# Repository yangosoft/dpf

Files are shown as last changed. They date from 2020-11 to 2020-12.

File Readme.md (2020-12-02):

# Diesel Filter Particle viewer

Only tested in a Volkswagen 2.0 TDI CAGA engine.

The code is mostly based on https://github.com/fkoca5055/obdESP with some changes to check DFP status, provide a WiFi Access Point to change Bluetooth device, PIN, debug viewer...

Please note: as I'm not having so much time to spend on this project the code is quick and dirty.

## Needed parts

 - ESP32 NodeMCU ESP-32s
 - TFT Screen based on ILI9341
 - ELM327 Bluetooth

## Box and schema

 - [PCB](schema/dpf1) designed with EAGLE.
 - [Box to 3d print](schema/3dmodel) designed with FreeCAD.

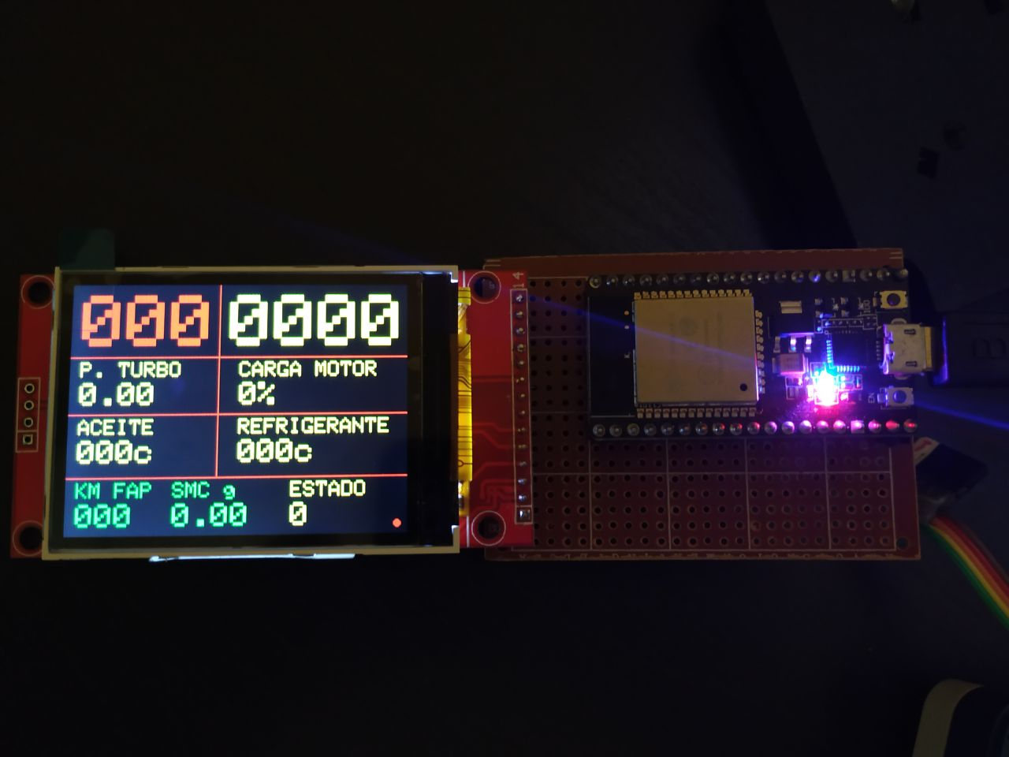
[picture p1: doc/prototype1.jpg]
Prototype1

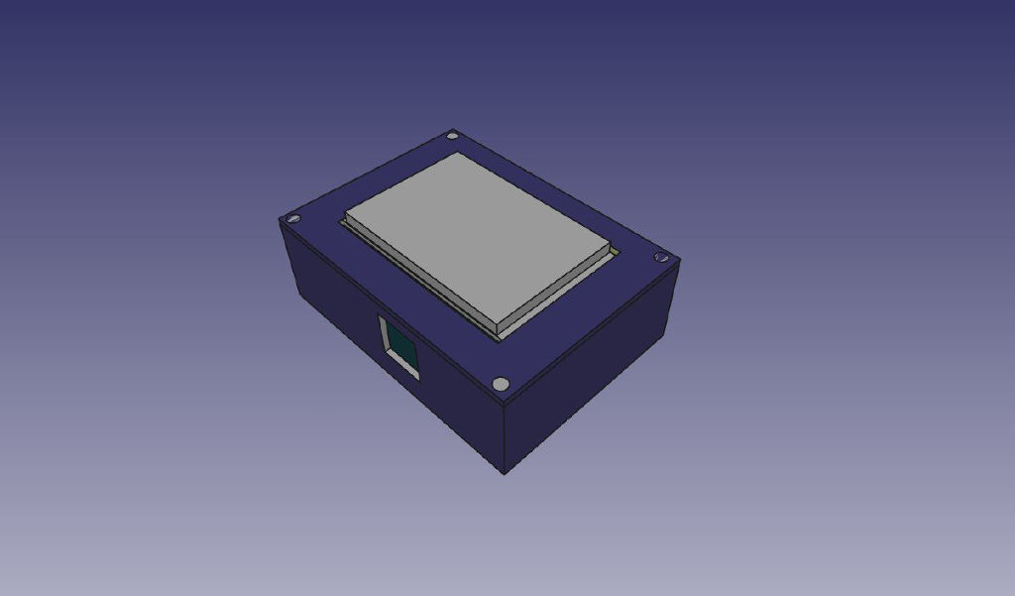
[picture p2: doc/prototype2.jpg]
Prototype2

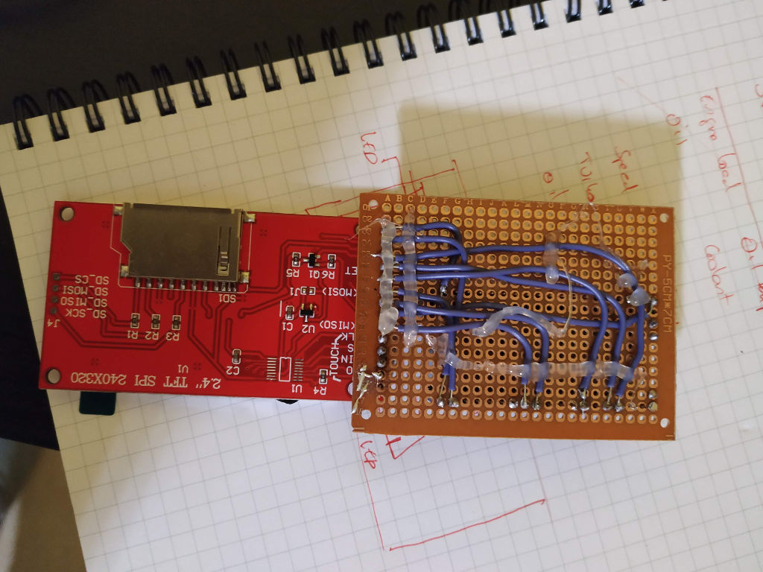
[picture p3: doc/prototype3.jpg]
Prototype3

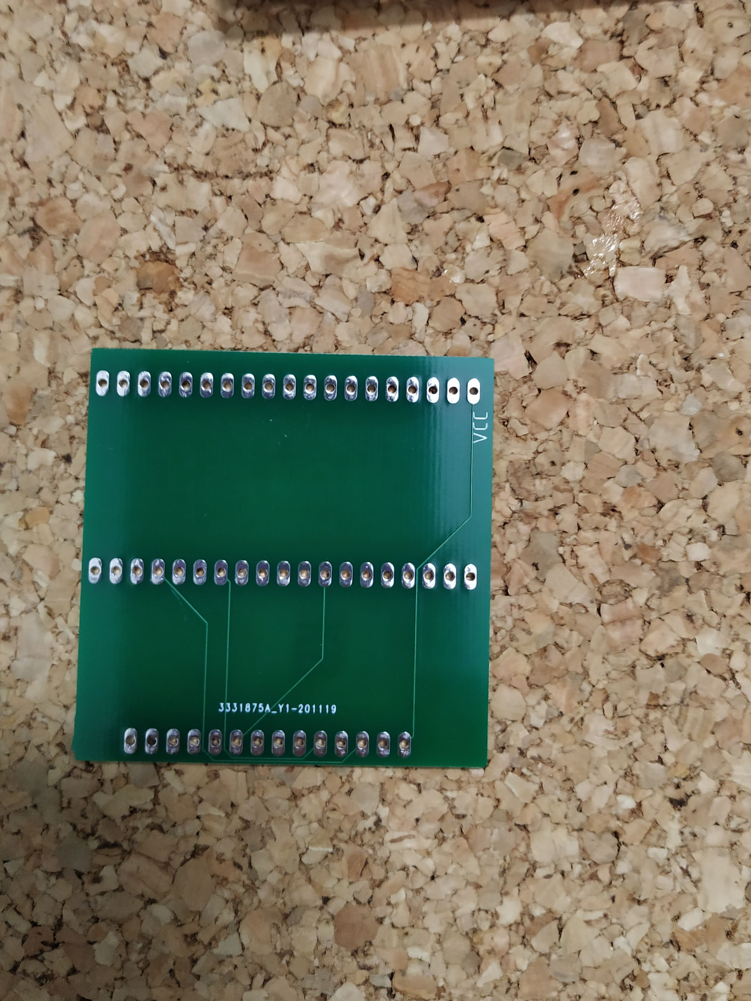
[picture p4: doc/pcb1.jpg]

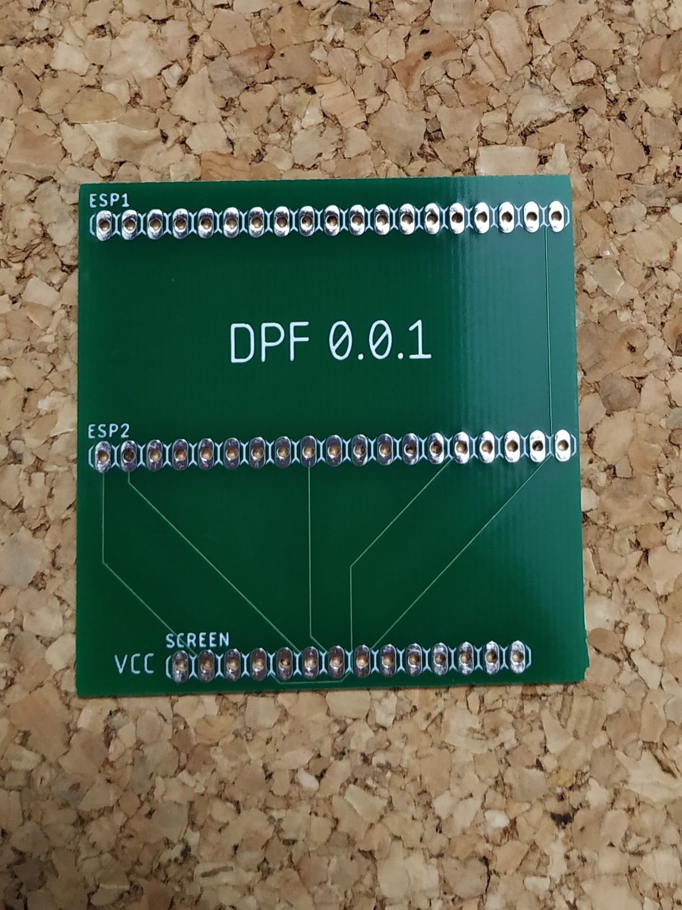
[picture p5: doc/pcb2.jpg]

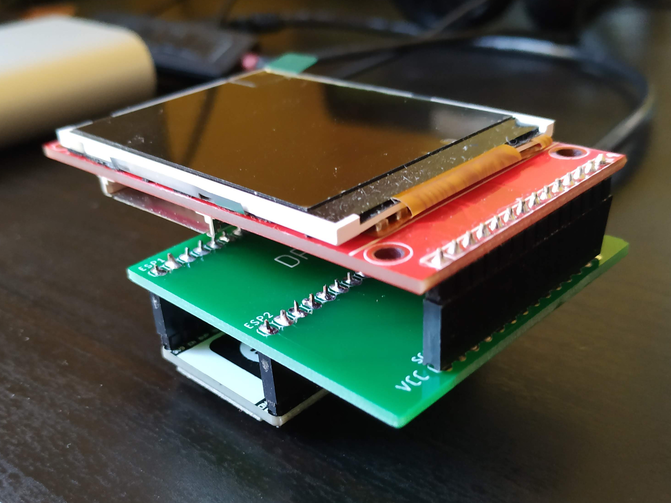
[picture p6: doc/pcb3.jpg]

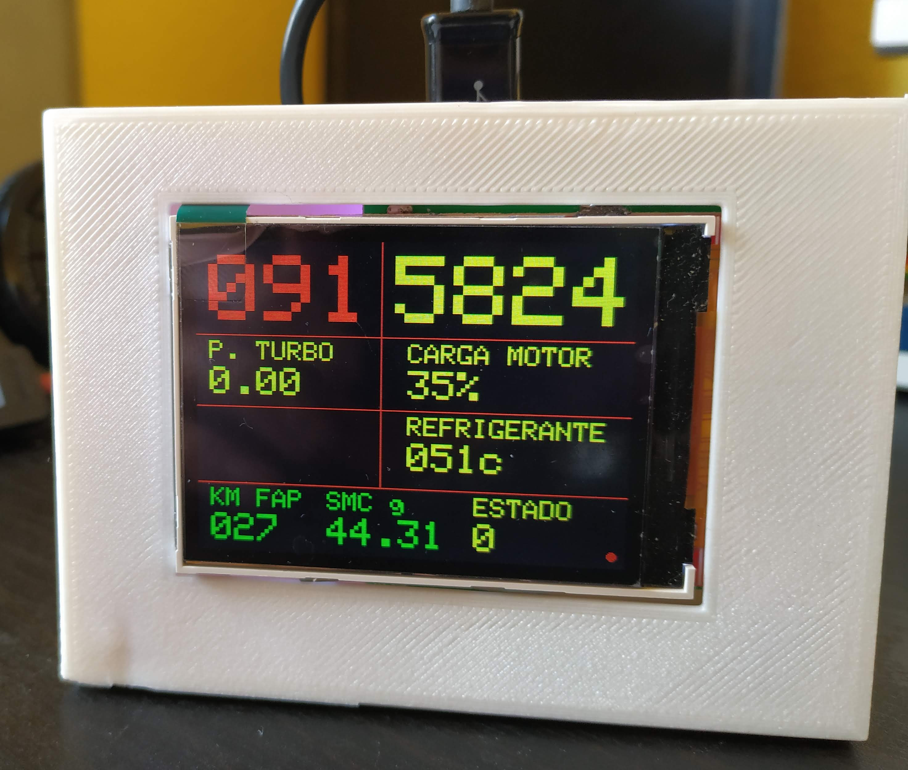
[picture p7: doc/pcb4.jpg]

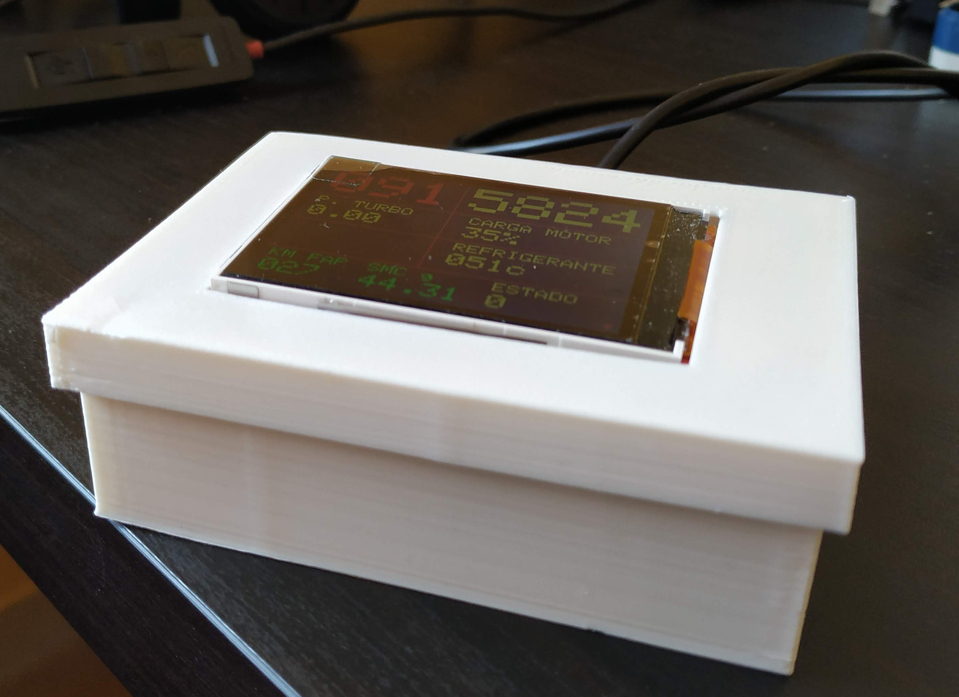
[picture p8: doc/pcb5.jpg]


## Pinout

|  TFT | ESP32 GPIO |
|---|---|
| TFT_CS | 15 |
| TFT_DC | 4 |
| TFT_MOSI | 23 |
| TFT_SLK | 18 |
| TFT_RST | 2 |
| TFT_LED | -1 |
| TFT_MISO | 19 |

Please change `TFT_RST` to another GPIO since this the integrated led in `NodeMCU ESP-32s`.

# Next steps

Remove the screen and make use of the FIS to display DFP information

# Useful links

- https://stackoverflow.com/questions/23877761/sniffing-logging-your-own-android-bluetooth-traffic
- https://forums.tdiclub.com/index.php?threads/reading-soot-level-with-torque.464119/page-4
- https://github.com/fkoca5055/obdESP/blob/master/2.4_LCD.ino
- https://www.cardumps.net/account/my-profile
- https://stackoverflow.com/questions/23877761/sniffing-logging-your-own-android-bluetooth-traffic
- http://jakubdziworski.github.io/obd/bluetooth/arduino/car/2020/07/13/arduino-obd-dpf-monitor-insignia.html
- http://www.areavag.com/foro/showthread.php?42159-Regeneraci%F3n-filtro-part%EDculas-diagnosis-con-iPhone/page3
- https://gist.github.com/0/c73e2557d875446b9603
- https://stackoverrun.com/es/q/12573350
- http://jakubdziworski.github.io/
- https://scribles.net/setting-up-bluetooth-serial-port-profile-on-raspberry-pi/
- https://forum.fairphone.com/t/location-of-btsnoop-hci-log-file/60320
- https://www.fte.com/WebHelpII/Sodera/Content/Documentation/WhitePapers/BPA600/Encryption/GettingAndroidLinkKey/RetrievingHCIlog.htm
- https://stackoverflow.com/questions/23877761/sniffing-logging-your-own-android-bluetooth-traffic
- https://github.com/fkoca5055/obdESP
- https://github.com/ibanezgomez/FISBlocks

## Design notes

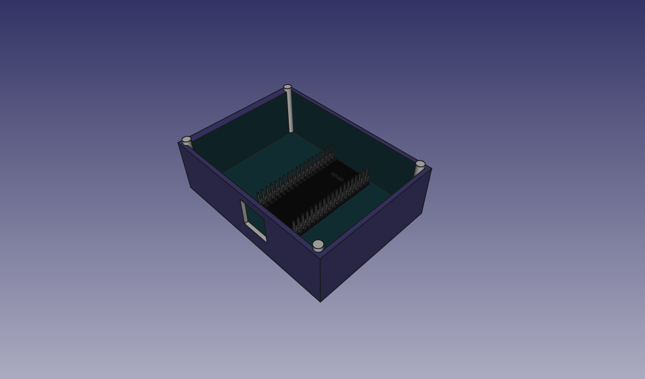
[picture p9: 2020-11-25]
schema/3dmodel/complete3.png

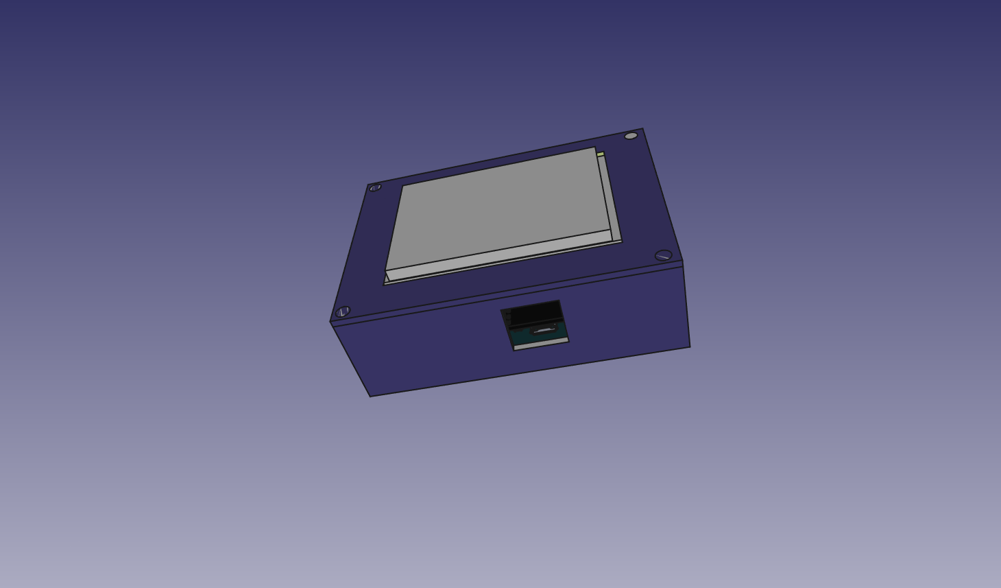
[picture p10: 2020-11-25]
schema/3dmodel/complete5.png

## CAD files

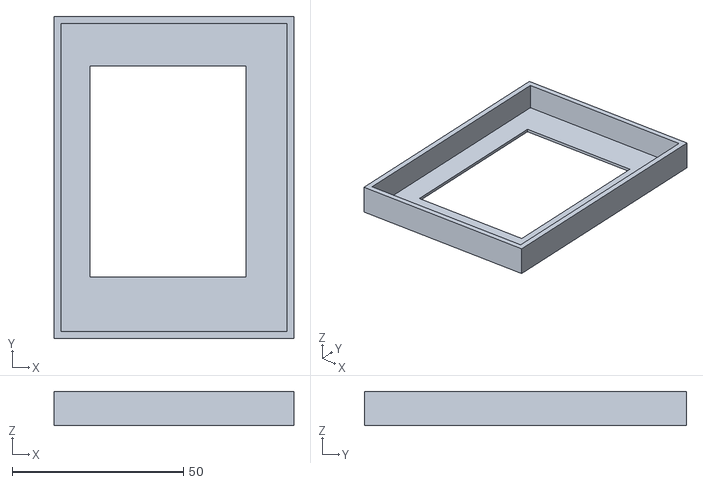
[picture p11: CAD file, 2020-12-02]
schema/3dmodel/outbox1-v4.stl
70.0 x 94.0 x 10.0

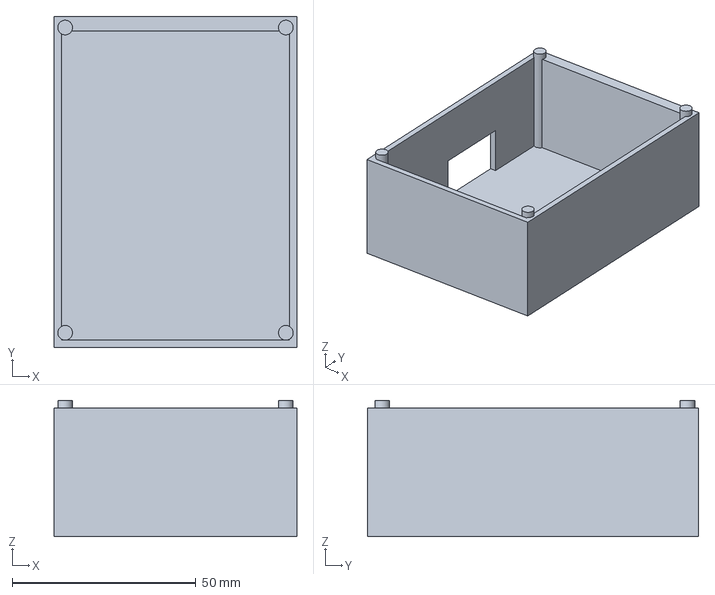
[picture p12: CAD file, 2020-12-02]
schema/3dmodel/outbox2-v2.FCStd
66.0 x 90.0 x 37.0 mm

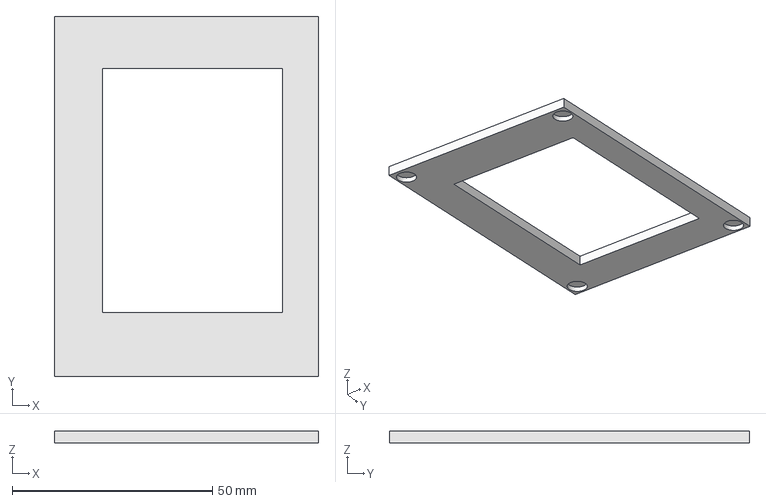
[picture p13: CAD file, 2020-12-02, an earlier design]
schema/3dmodel/outbox1-v2.FCStd
66.0 x 90.0 x 3.00 mm

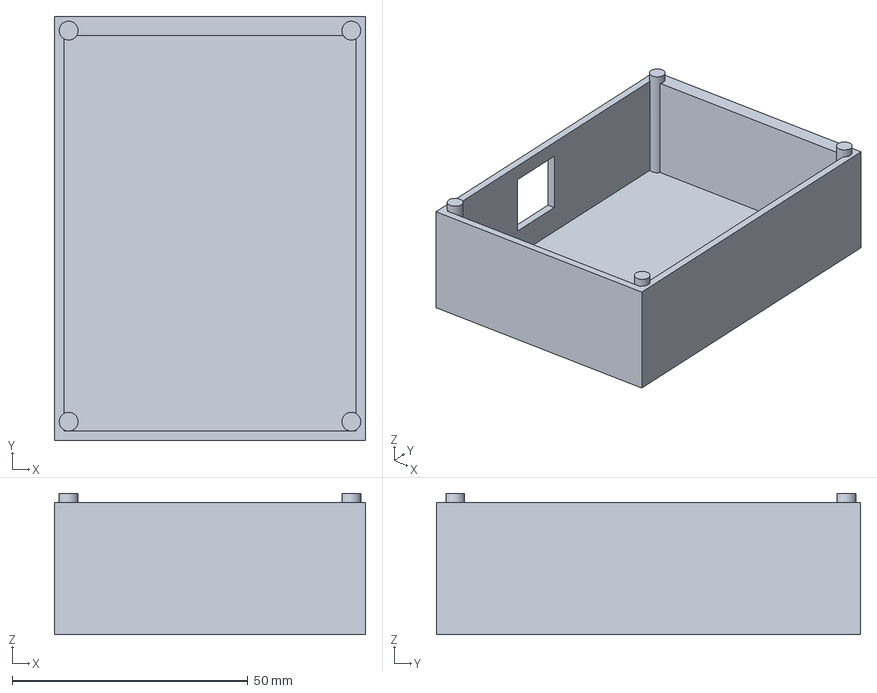
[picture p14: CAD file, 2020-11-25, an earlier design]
schema/3dmodel/outbox2.FCStd
66.0 x 90.0 x 30.0 mm

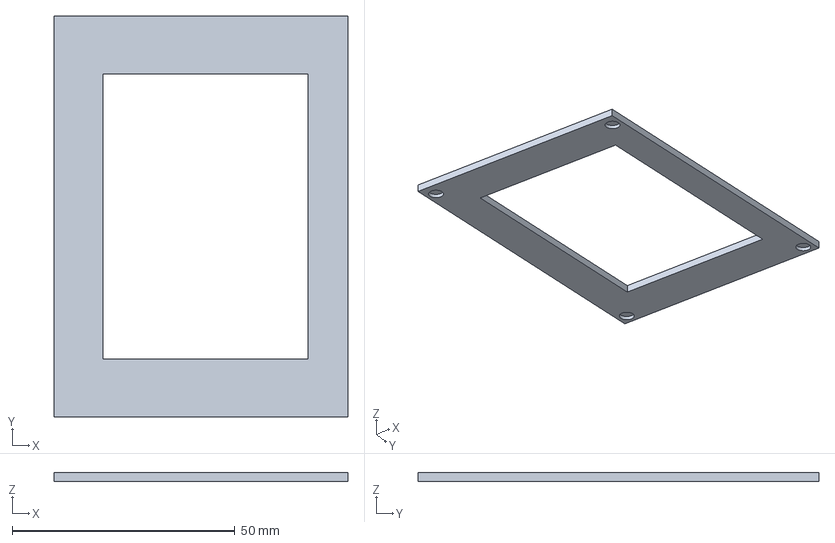
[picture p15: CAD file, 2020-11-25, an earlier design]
schema/3dmodel/outbox1.FCStd
66.0 x 90.0 x 2.00 mm

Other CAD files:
schema/3dmodel/outbox1-v3.FCStd
schema/3dmodel/outbox1-v2.stl
schema/3dmodel/outbox1-v3.stl
schema/3dmodel/outbox1.stl
schema/3dmodel/outbox2-v2.stl
schema/3dmodel/outbox2.stl

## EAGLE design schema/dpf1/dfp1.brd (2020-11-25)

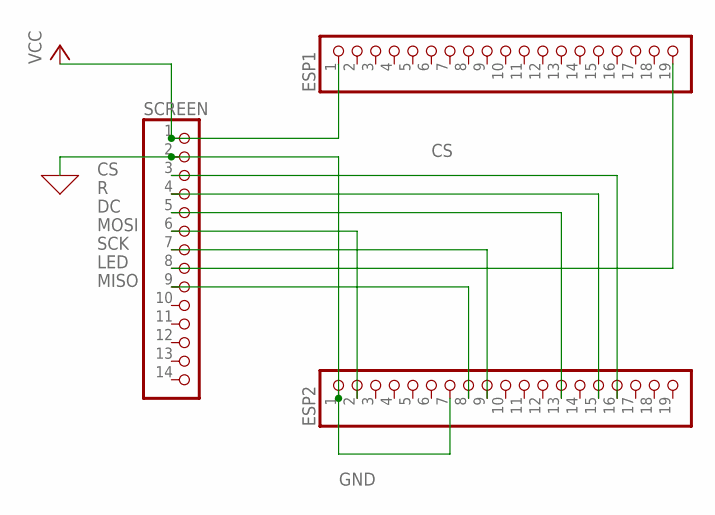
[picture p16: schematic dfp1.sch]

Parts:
ESP1, ESP2: PINHD-1X19; 1X19
SCREEN: PINHD-1X14; 1X14

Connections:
CS: ESP2.16, SCREEN.3
DC: ESP2.13, SCREEN.5
GND: ESP2.1, ESP2.7, SCREEN.2
LED: ESP1.19, SCREEN.8
MISO: ESP2.8, SCREEN.9
MOSI: ESP2.2, SCREEN.6
R: ESP2.15, SCREEN.4
SCK: ESP2.9, SCREEN.7
VCC: ESP1.1, SCREEN.1

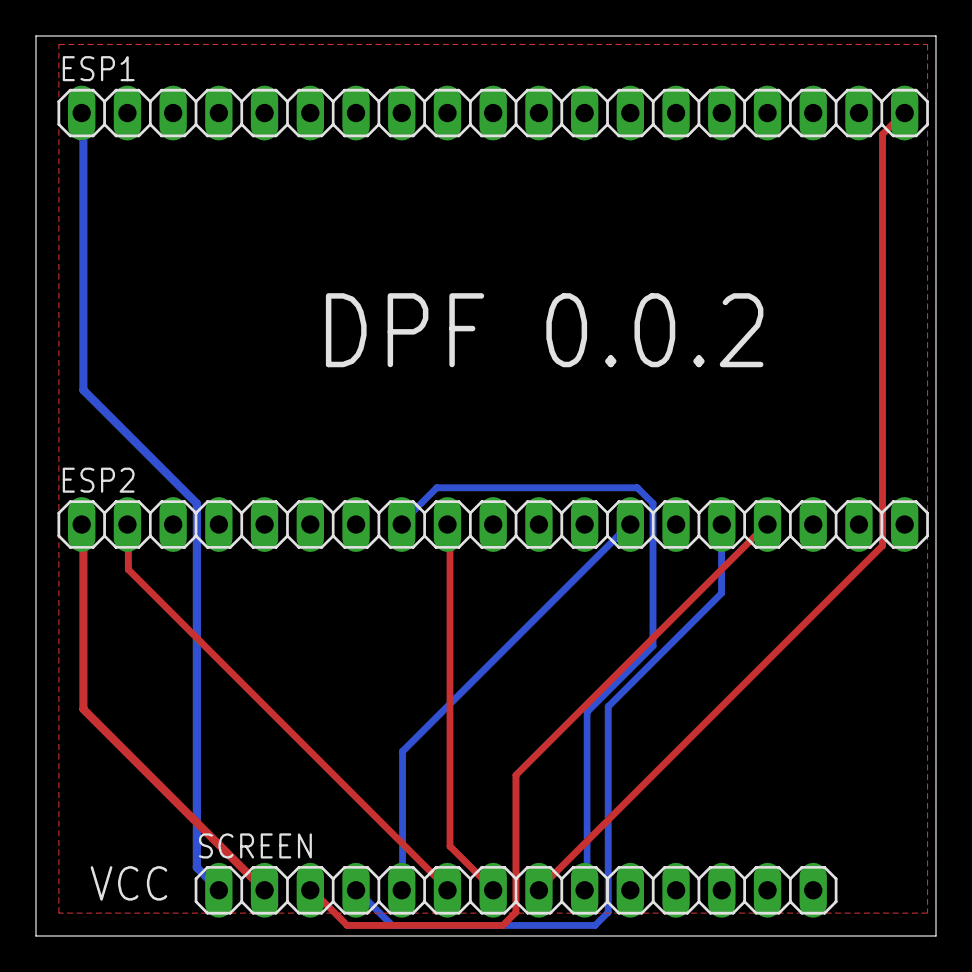
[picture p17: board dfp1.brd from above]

Board: 2 copper layers, 50.0 x 50.0 mm, 3 parts (0 on the bottom side), 9 nets.

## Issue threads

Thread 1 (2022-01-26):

Question about values

Dropsik, 2022-01-26:
Hi. I ported yours code into Arduino and it works pretty well (but it's more dirty :) )
I can't figure, why I'm getting few values (and I'm not sure it's a problem with code or PIDs).

- turboPRESS always show value >=1.0 (even when engine is off, it showing 1.0)
- oilTemp show always -30 (even FIS showing >70)
and the bigger mess, is when I try call getSMC() - everywhere I got wrong values (like 2524 for RPM when I don't touch throttle) - for few second I see good values.
I'm working with Audi A4 B8 (CNHA engine)

yangosoft, 2022-01-27:
Hi!

Check the data that you are getting.

Print the bytes one to one and try to do the calculations by hand.

It could be also that your OBD2 dongle is not sending the data.

I'm not totally sure if B8  PIDs are different from B7 but at least the standard one must be the same.

BR,
yango

Dropsik, 2022-01-27:
After few tests:
- oilTemp is not supported in my car
- getSMC() function retrieve correct value (checked with VCDS), but after call this funtion it's completly stop refreshing data.

Dropsik, 2022-01-27:
Ok, I made a little debuging
getRpm();
getSpeed();
getBattery();
getTurboPressure();
getEngineLoad();
getEGT();
getCoolant();
works perfect and give reliable data until I call getSMC();
SEND_BLE("ATSH7E0\r"); cause that I got reliable data for DPF, but completly random for these above.

yangosoft, 2022-01-28:
Make sure you only send ATSH7E0 once. This sets the ELM327 to use 7bits CAN messages, if I'm not wrong.

And remember to reset all stored values in ELM327.

Dropsik, 2022-01-28:
I'm using initODB() from your code - so ATD is sent.
And funny thing - you send ATSH7E0 twice ;)
https://github.com/yangosoft/dpf/blob/master/src/dpf.cpp#L275
https://github.com/yangosoft/dpf/blob/master/src/dpf.cpp#L487

Dropsik, 2022-01-29:
My source code:
https://github.com/Dropsik/dpf/blob/master/arduino/obd2/obd2.ino

yangosoft, 2022-02-08:
@Dropsik did you manage to get fully working?

Dropsik, 2022-02-09:
Unfortunately no.
I assume, that my elm327 adapter is ok (works with android app and show values). But I have no idea how to resolve problem

Dropsik, 2022-02-14:
@yangosoft If you have any ideas or maybe the can try my code I'll be appreciated help.

yangosoft, 2022-02-14:
Sadly I sold my nice car a few months ago and I don't have access to a CAGA engine.

Try to debug the Bluetooh traffic between an app and the device: https://stackoverflow.com/questions/23877761/sniffing-logging-your-own-android-bluetooth-traffic this should give you a hint about the correct sequence of commands.

Closed 2023-04-04.

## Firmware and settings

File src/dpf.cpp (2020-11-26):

#include "dpf.hpp"

Adafruit_ILI9341 tft = Adafruit_ILI9341(TFT_CS, TFT_DC, TFT_MOSI, TFT_SLK, TFT_RST, TFT_MISO);

char rxData[READ_BUFFER_SIZE];
uint8_t rxIndex = 0;

int rpm, LDR, LDRMAX, LDRMIN, EGT, turboRAW, reading, COOLANT, x, engineLoad, oilTemp;
uint32_t speed;
byte INTEMP, CACT, SPEED;
float BATTERY, turboPRESS, turboMAX;

unsigned long time_now2 = 0;
unsigned long period2 = 10000; 
unsigned long time_now5 = 0;
unsigned long period5 = 30000; 
unsigned long delayTime = 0;   

uint16_t SMC;
uint32_t km;
uint8_t percentFap;

char iBuf[16] = {};
char eBuf[16] = {};
char cBuf[16] = {};
char oBuf[16] = {};


BluetoothSerial SerialBT;

String name = "obd-2";
String pin = "1234";

String WIFI_CLIENT;
String WIFI_CLIENT_PASS;
String LOCAL_NAME;

AsyncWebServer server(80);
AsyncWebSocket ws("/ws");

void writeFile(fs::FS &fs, const char *path, const char *message)
{
  //Serial.printf("Writing file: %s\r\n", path);
  File file = fs.open(path, "w");
  if (!file)
  {
    //Serial.println("- failed to open file for writing");
    return;
  }

  file.print(message);
}

String readFile(fs::FS &fs, const char *path)
{
  //Serial.printf("Reading file: %s\r\n", path);
  File file = fs.open(path, "r");
  if (!file)
  {
    Serial.println("- empty file or failed to open file");

    return String();
  }
  //Serial.println("- read from file:");
  String fileContent;
  while (file.available())
  {
    fileContent += String((char)file.read());
  }
  //Serial.println(fileContent);
  return fileContent;
}

void handleRoot(AsyncWebServerRequest *request)
{
  request->send_P(200, "text/html", FRM_PASS);
}

void handleSave(AsyncWebServerRequest *request)
{
  if (request->hasParam(PARAM_INPUT_1))
  {
    WIFI_CLIENT = request->getParam(PARAM_INPUT_1)->value();
    writeFile(SPIFFS, "/wifi1", WIFI_CLIENT.c_str());
  }

  if (request->hasParam(PARAM_INPUT_2))
  {
    WIFI_CLIENT_PASS = request->getParam(PARAM_INPUT_2)->value();
    writeFile(SPIFFS, "/wifi2", WIFI_CLIENT_PASS.c_str());
  }

  if (request->hasParam(PARAM_INPUT_3))
  {
    LOCAL_NAME = request->getParam(PARAM_INPUT_3)->value();
    writeFile(SPIFFS, "/wifi3", LOCAL_NAME.c_str());
  }

  char buffer[256];
  snprintf(buffer, 256, "%s %s %s", WIFI_CLIENT.c_str(), WIFI_CLIENT_PASS.c_str(), LOCAL_NAME.c_str());

  request->send_P(200, "text/html", buffer);
}

void getStoredParams()
{
  WIFI_CLIENT = readFile(SPIFFS, "/wifi1");
  WIFI_CLIENT_PASS = readFile(SPIFFS, "/wifi2");
  LOCAL_NAME = readFile(SPIFFS, "/wifi3");

  Serial.print("WIFI_CLIENT: ");
  Serial.println(WIFI_CLIENT);
  Serial.print("WIFI_CLIENT_PASS: ");
  Serial.println(WIFI_CLIENT_PASS);
  Serial.print("LOCAL_NAME: ");
  Serial.println(LOCAL_NAME);
  if (LOCAL_NAME == "")
  {
    LOCAL_NAME = "obd-2";
  }

  if (WIFI_CLIENT == "")
  {
    WIFI_CLIENT = "1234";
  }
}

void onEvent(AsyncWebSocket *server, AsyncWebSocketClient *client, AwsEventType type, void *arg, uint8_t *data, size_t len)
{
  switch (type)
  {
  case WS_EVT_CONNECT:
    Serial.printf("WebSocket client #%u connected from %s\n", client->id(), client->remoteIP().toString().c_str());
    break;
  case WS_EVT_DISCONNECT:
    Serial.printf("WebSocket client #%u disconnected\n", client->id());
    break;
  case WS_EVT_DATA:
    //handleWebSocketMessage(arg, data, len);
    break;
  case WS_EVT_PONG:
  case WS_EVT_ERROR:
    break;
  }
}

void setup()
{
  Serial.begin(115200);

  if (!SPIFFS.begin())
  {
    Serial.println("An Error has occurred while mounting SPIFFS");
  }
  Serial.println("Get params()");
  getStoredParams();
  Serial.println("OK!");
  name = LOCAL_NAME;
  pin = WIFI_CLIENT;
  Serial.println("ACCESS POINT MODE");
  Serial.print("Configuring access point...");
  WiFi.softAP(ssid, password);

  IPAddress myIP = WiFi.softAPIP();
  Serial.print("AP IP address: ");
  Serial.println(myIP);
  server.on("/", HTTP_GET, handleRoot);
  server.on("/save", HTTP_GET, handleSave);
  ws.onEvent(onEvent);
  server.addHandler(&ws);
  server.begin();

  SerialBT.begin("dpfread", true);
  SerialBT.setPin(pin.c_str());

  tft.begin();
  tft.setRotation(1);
  tft.fillScreen(ILI9341_WHITE);

  tft.setCursor(250, 230);
  tft.setTextSize(1);
  tft.setTextColor(ILI9341_BLACK, ILI9341_WHITE);
  tft.print(VERSION);

  tft.setCursor(0, 20);
  tft.setTextSize(2);
  tft.setTextColor(ILI9341_BLACK, ILI9341_WHITE);

  tft.print("WIFI: ");
  tft.print(ssid);
  tft.print("\n\nPASS: ");
  tft.print(password);
  tft.print("\n\n");

  tft.print("Bluetooth: ");
  tft.print(name);
  tft.print("\n\nPIN: ");
  tft.print(pin);
  tft.print("\n\n");

  delay(5000);

  bool connected = SerialBT.connect(name);
  while (connected == false)
  {
    Serial.println("Connecting...");
    delay(500);
  }
  tft.fillScreen(ILI9341_WHITE);
  tft.setCursor(0, 10);
  tft.setTextSize(1);
  //SerialBT.flush();
  Serial.println("Init ODB");
  tft.print("Init ELM327\n\n");
  initODB();
  tft.fillScreen(ILI9341_BLACK);

  tft.drawLine(0, 70, 320, 70, ILI9341_RED);
  tft.drawLine(0, 125, 320, 125, ILI9341_RED);
  tft.drawLine(0, 185, 320, 185, ILI9341_RED);
  tft.drawLine(140, 0, 140, 185, ILI9341_RED);

  drawScreen(false);
}

void loop()
{
  ws.cleanupClients();
  getRpm();
  getSpeed();
  getTurboPressure();
  getEngineLoad();

  if (millis() > time_now2 + period2)
  {
    //getIntakeTemperature();
    getCoolant();
    getOilTemp();
    time_now2 = millis();
    //drawScreen(false);
  }
  else if (millis() > time_now5 + period5)
  {
    getSMC();
    time_now5 = millis();
    drawScreen(false);
  }
  else
  {
    drawScreen(true);
  }
}

void initODB()
{
  delay(0); //1000
  SEND_BLE("ATZ\r");
  delay(500); //2000
  readOBD();
  SEND_BLE("ATD\r");
  delay(500); //2000
  readOBD();
  tft.print(rxData);
  tft.print("\n");
  SEND_BLE("ATE0\r");
  delay(500); //1000
  readOBD();
  tft.print(rxData);
  tft.print("\n");
  SEND_BLE("ATSP6\r");
  delay(500); //1000
  readOBD();
  tft.print(rxData);
  tft.print("\n");
  SEND_BLE("ATSH7E0\r");
  delay(700);
  readOBD();
  tft.print(rxData);
  tft.print("\n");
  //SerialBT.flush();
}

void drawScreen(bool half)
{
  static int randomColor = 0;
 

  tft.setCursor(10, 10);
  tft.setTextColor(ILI9341_RED, ILI9341_BLACK);
  tft.setTextSize(7);
  snprintf(oBuf, sizeof(oBuf), "%03d", speed);
  tft.print(oBuf);

  tft.setCursor(150, 10);
  tft.setTextColor(ILI9341_YELLOW, ILI9341_BLACK);
  tft.setTextSize(7);
  snprintf(oBuf, sizeof(oBuf), "%04d", rpm);
  tft.print(oBuf);

  tft.setCursor(10, 75);
  tft.setTextSize(2);
  tft.print("P. TURBO");

  tft.setCursor(10, 95);
  tft.setTextSize(3);
  tft.print(turboPRESS, 2);

  tft.setTextSize(2);
  tft.setCursor(160, 75);
  tft.setTextColor(ILI9341_YELLOW, ILI9341_BLACK);
  tft.print("CARGA MOTOR");

  tft.setTextSize(3);
  tft.setCursor(160, 95);
  tft.setTextColor(ILI9341_YELLOW, ILI9341_BLACK);
  tft.print(engineLoad);
  tft.print("%");

  if (randomColor % 2)
  {
    tft.fillCircle(310, 230, 3, ILI9341_BLACK);
  }
  else
  {
    tft.fillCircle(310, 230, 3, ILI9341_RED);
  }

  randomColor++;

  if (half == true)
  {
    return;
  }

  /* Not supported :(
  tft.setCursor(10, 130);
  tft.setTextSize(2);
  tft.print("ACEITE");
  tft.setTextSize(3);
  tft.setCursor(10, 150);
  snprintf(oBuf, sizeof(oBuf), "%03d", oilTemp);
  tft.print(oBuf);
  tft.println("c");*/

  tft.setCursor(160, 130);
  tft.setTextSize(2);
  tft.print("REFRIGERANTE");
  tft.setTextSize(3);
  tft.setCursor(160, 150);
  snprintf(oBuf, sizeof(oBuf), "%03dc", COOLANT);
  tft.print(oBuf);

  tft.setCursor(210, 190);
  tft.setTextSize(2);
  tft.print("ESTADO");

  tft.setCursor(210, 210);
  tft.setTextSize(3);
  tft.print(percentFap);

  float SMCF = SMC;
  SMCF = SMCF / 100;
  tft.setTextColor(ILI9341_GREEN, ILI9341_BLACK);
  tft.setTextSize(2);
  tft.setCursor(100, 190);
  tft.print("SMC g");
  tft.setTextSize(3);
  char buffer[16];
  snprintf(buffer, 16, "%.2f", SMCF);
  tft.setCursor(100, 210);
  tft.print(buffer);

  tft.setTextColor(ILI9341_GREEN, ILI9341_BLACK);
  tft.setTextSize(2);
  tft.setCursor(10, 190);
  tft.print("KM FAP");
  tft.setTextSize(3);
  tft.setCursor(10, 210);
  snprintf(buffer, 16, "%03d", km);
  tft.print(buffer);
}

void getRpm()
{
  SerialBT.flush();
  SEND_BLE("010C\r");
  delay(delayTime);
  readOBD();
  rpm = ((strtol(&rxData[6], 0, 16) * 256) + strtol(&rxData[9], 0, 16)) / 4;
}

void getEngineLoad()
{
  SerialBT.flush();
  SEND_BLE("0104\r");
  delay(delayTime);
  readOBD();
  engineLoad = (strtol(&rxData[6], 0, 16) * 100) / 255;
}

void getCoolant()
{
  SerialBT.flush();
  SEND_BLE("0105\r");
  delay(delayTime);
  readOBD();
  COOLANT = strtol(&rxData[6], 0, 16) - 40;
}

//
void getOilTemp()
{
  SerialBT.flush();
  SEND_BLE("015C\r");
  delay(delayTime);
  readOBD();
  oilTemp = strtol(&rxData[6], 0, 16) - 40;
}

void getIntakeTemperature()
{
  SerialBT.flush();
  SEND_BLE("010F\r");
  delay(delayTime);
  readOBD();
  INTEMP = strtol(&rxData[6], 0, 16) - 40;
  tft.setCursor(220, 0);
  tft.setTextColor(ILI9341_GREEN, ILI9341_BLACK);
  tft.setTextSize(2);
  tft.print("T. AIRE");
  tft.setTextSize(3);
  tft.setCursor(225, 25);
  snprintf(iBuf, sizeof(iBuf), "%3d", INTEMP);
  tft.println(iBuf);
  tft.setCursor(290, 25);
  tft.println("c");
  tft.drawCircle(285, 25, 3, ILI9341_GREEN);
}

void getCACT()
{
  SerialBT.flush();
  SEND_BLE("0177\r");
  delay(delayTime);
  readOBD();
  CACT = strtol(&rxData[9], 0, 16) - 40;
  tft.setCursor(120, 60);
  tft.setTextColor(ILI9341_GREEN, ILI9341_BLACK);
  tft.setTextSize(2);
  tft.print("T ICOOL");
  tft.setTextSize(3);
  tft.setCursor(125, 85);
  snprintf(cBuf, sizeof(cBuf), "%3d", CACT);
  tft.println(cBuf);
  //tft.println(CACT)+tft.print((char)247)+tft.print("C");
  tft.setCursor(190, 85);
  tft.println("c");
  tft.drawCircle(185, 85, 3, ILI9341_GREEN);
}

void getBattery()
{
  SerialBT.flush();
  SEND_BLE("0142\r");
  delay(delayTime);
  readOBD();
  BATTERY = ((strtol(&rxData[6], 0, 16) * 256) + strtol(&rxData[9], 0, 16)); //((A*256)+B)/1000
  BATTERY = BATTERY / 1000;
  if (BATTERY < 12)
  {
    tft.setTextColor(ILI9341_BLACK, ILI9341_YELLOW);
  }
  else
  {
    tft.setTextColor(ILI9341_GREEN, ILI9341_BLACK);
  }
  tft.setCursor(0, 60);
  tft.setTextSize(2);
  tft.print(BATTERY, 1);
  tft.println("v");
}

//SOOT MASS CALC
void getSMC()
{
  SerialBT.flush();
  SEND_BLE("ATSH7E0\r");
  delay(200);
  readOBD();
  SEND_BLE("0100\r");
  delay(200);
  readOBD();
  SEND_BLE("22114F\r");
  delay(200);
  readOBD();

   SMC = ((strtol(&rxData[9], 0, 16) * 256) + strtol(&rxData[12], 0, 16)); //((A*256)+B)/100

  //SerialBT.println(SMC);

  //KM
  SEND_BLE("221156\r");
  delay(200);
  readOBD();
  km = (strtol(&rxData[9], 0, 16) << 24) + (strtol(&rxData[12], 0, 16) << 16 ) +  (strtol(&rxData[15], 0, 16) << 8) + strtol(&rxData[18], 0, 16); 
  Serial.print("\nKM: ");
  SerialBT.println(km);
  km = km / 1000;

  //Percent
  SEND_BLE("22115B\r");
  delay(200);
  readOBD();


  percentFap = strtol(&rxData[9], 0, 16);
}

void getEGT()
{
  SerialBT.flush();
  SEND_BLE("0178\r");
  delay(100);
  readOBD();
  EGT = (((strtol(&rxData[30], 0, 16) * 256) + strtol(&rxData[33], 0, 16)) / 10) - 40;
  if (EGT < 350)
  {
    tft.setTextColor(ILI9341_GREEN, ILI9341_BLACK);
    tft.drawCircle(185, 25, 3, ILI9341_GREEN);
    tft.fillCircle(190, 7, 7, ILI9341_BLACK);
  }
  else if ((EGT >= 350) && (EGT < 450))
  {
    tft.setTextColor(ILI9341_YELLOW, ILI9341_BLACK);
    tft.drawCircle(185, 25, 3, ILI9341_YELLOW);
    tft.fillCircle(190, 7, 7, ILI9341_YELLOW);
  }
  else if (EGT >= 450)
  {
    tft.setTextColor(ILI9341_RED, ILI9341_BLACK);
    tft.drawCircle(185, 25, 3, ILI9341_RED);
    tft.fillCircle(190, 7, 7, ILI9341_RED);
  }
  tft.setCursor(140, 0);
  tft.setTextSize(2);
  tft.print("EGT");
  tft.setTextSize(3);
  tft.setCursor(120, 25);
  snprintf(eBuf, sizeof(eBuf), "%3d", EGT);
  tft.println(eBuf);
  tft.setCursor(190, 25);
  tft.println("c");
}

int getSpeed()
{
  SerialBT.flush();
  SEND_BLE("010D\r");
  delay(delayTime);
  readOBD();
  speed = strtol(&rxData[6], 0, 16);
  return speed;
}

int getIntakePressure()
{
  SerialBT.flush();
  SEND_BLE("010B\r");
  delay(delayTime);
  readOBD();
  return strtol(&rxData[6], 0, 16);
}

int getBarometricPressure()
{
  /*Not supported
  SerialBT.flush();
  SEND_BLE("0133\r");
  delay(delayTime);
  readOBD();
  return strtol(&rxData[6], 0, 16);*/
  return 1; //Approx 1atm ~ 1bar
}

void getTurboPressure()
{
  turboRAW = (getIntakePressure() - getBarometricPressure());
  turboPRESS = turboRAW;
  turboPRESS = (turboPRESS * 0.01);
}

void readOBD()
{
  char c;
  do
  {
    if (SerialBT.available() > 0)
    {
      c = SerialBT.read();
      //lcd.print(c);
      if ((c != '>') && (c != '\r') && (c != '\n'))
      {
        rxData[rxIndex++] = c;
      }
      if (rxIndex > READ_BUFFER_SIZE)
      {
        rxIndex = 0;
      }
    }
  } while (c != '>'); //ELM327 response end
  rxData[rxIndex++] = '\0';
  rxIndex = 0;
  Serial.print("R:");
  Serial.println(rxData);
  ws.textAll("R:");
  ws.textAll(rxData);
  ws.textAll("\n");
}

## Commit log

2020-11-25 Added missing partition table
    [min_spiffs.csv]
2020-12-02 Added new box and images
    [outbox1-v2.FCStd, outbox1-v2.stl, outbox1-v3.FCStd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]
